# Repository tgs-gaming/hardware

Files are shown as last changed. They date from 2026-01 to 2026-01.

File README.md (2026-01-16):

# TGS Hardware

TGS Hardware Projects

[Documentation](docs/README.md)

## TGS INPUT board

[INPUT BOARD USAGE MANUAL](docs/tgs_input_board_usage_manual.md)

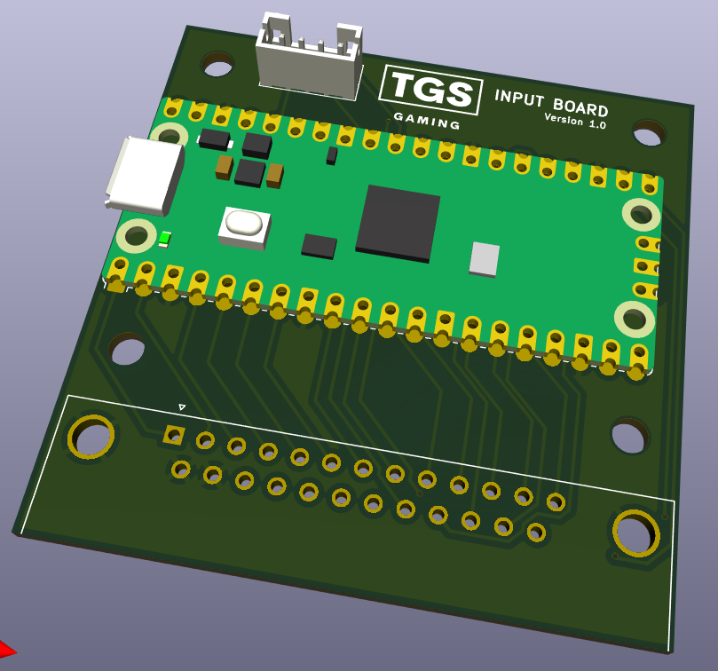
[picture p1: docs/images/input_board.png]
input board
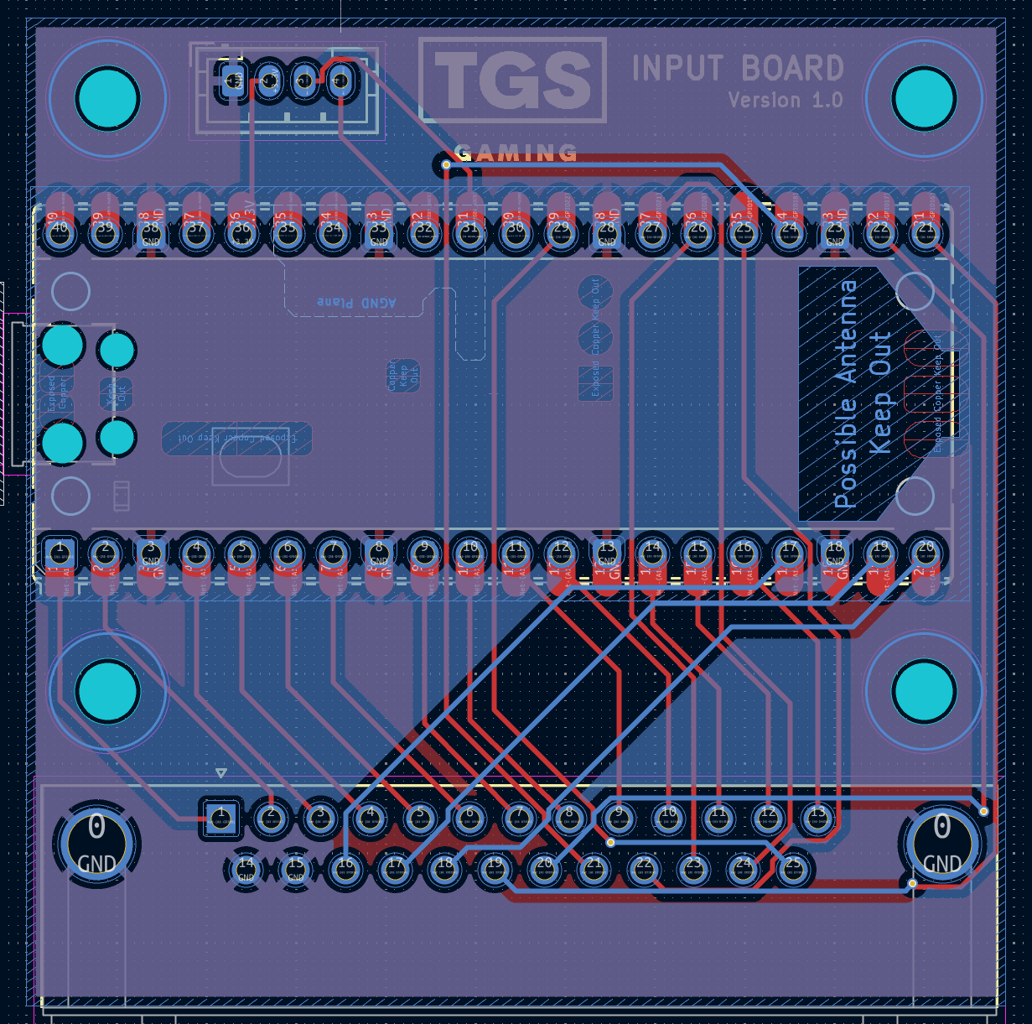
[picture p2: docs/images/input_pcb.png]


Board Configuration Tool

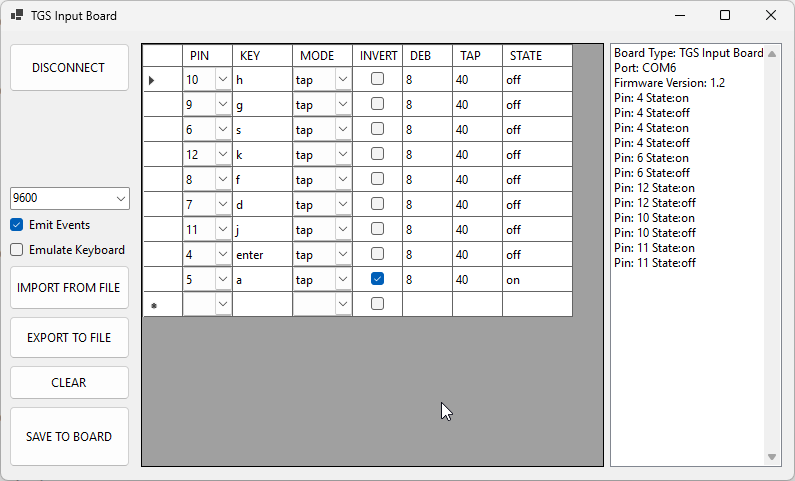
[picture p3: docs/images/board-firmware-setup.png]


## 

## TGS INPUT/OUTPUT board

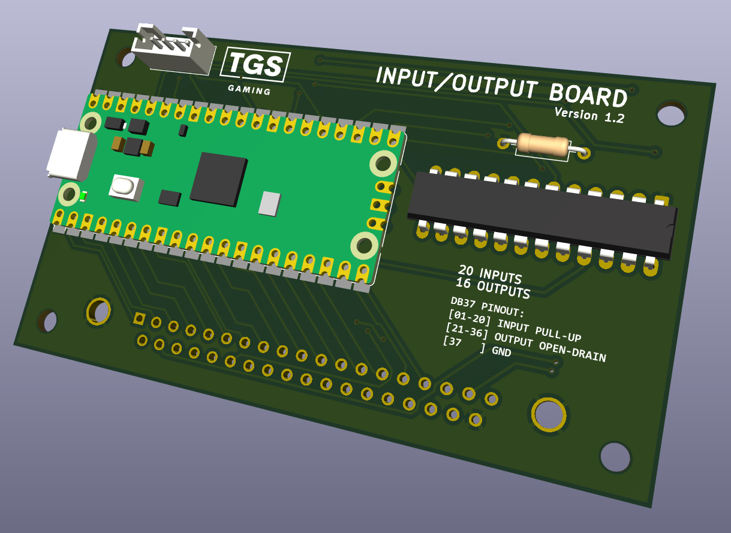
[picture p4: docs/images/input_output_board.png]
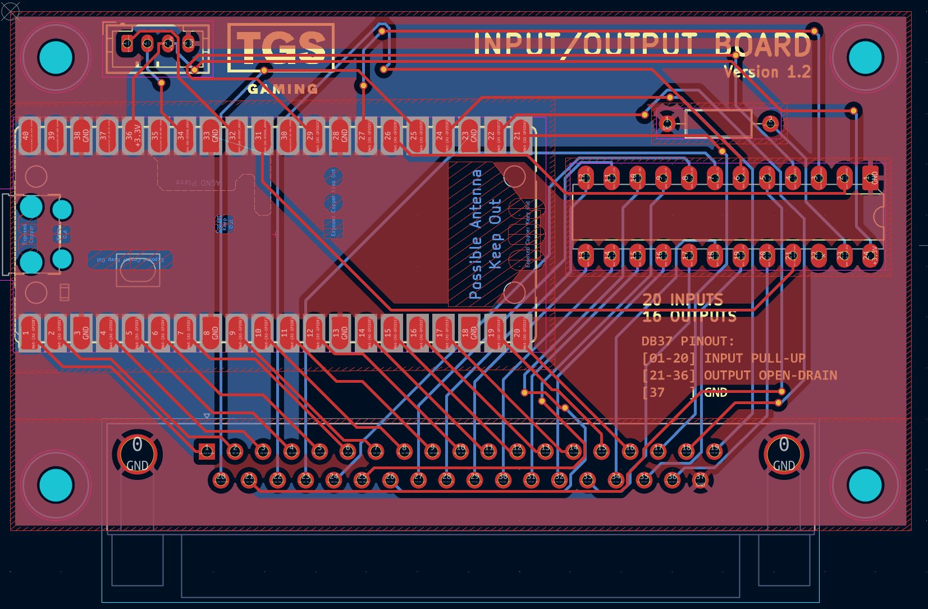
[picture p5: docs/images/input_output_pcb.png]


## TGS OUTPUT board

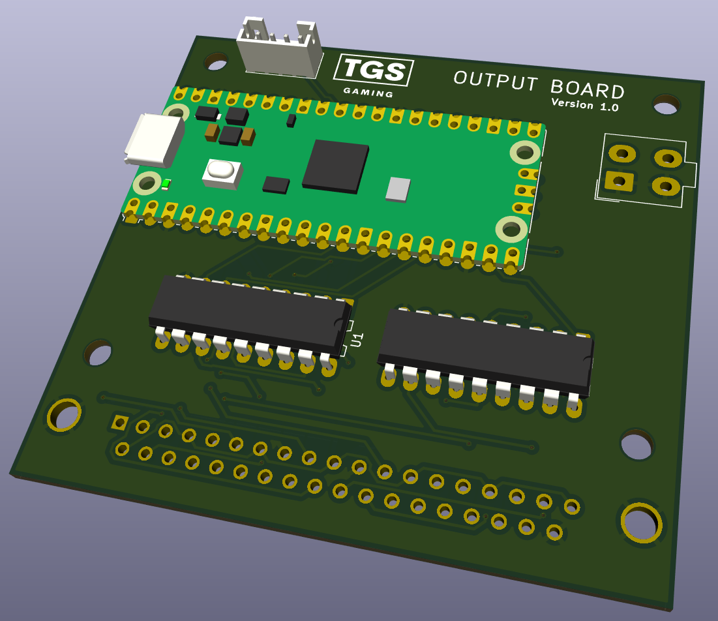
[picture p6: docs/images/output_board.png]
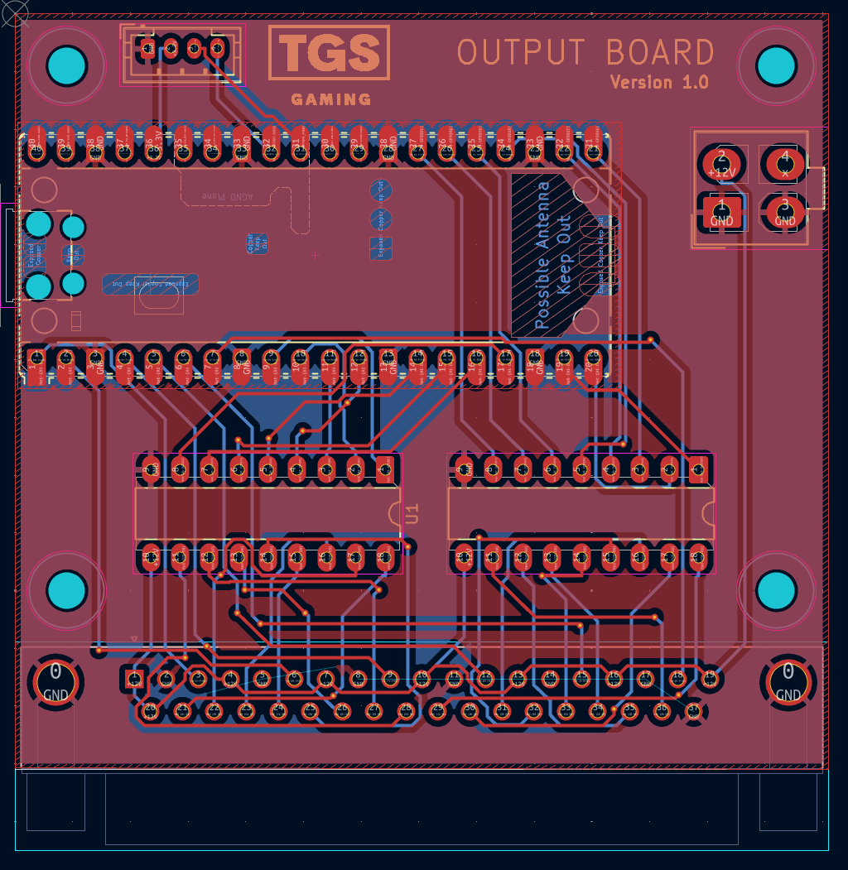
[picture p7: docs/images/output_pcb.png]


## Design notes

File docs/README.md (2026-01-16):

# Documentation

[INPUT BOARD USAGE MANUAL](docs/tgs_input_board_usage_manual.md)

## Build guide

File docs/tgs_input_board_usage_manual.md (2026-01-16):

# TGS Input Board - Usage Manual

Firmware name: TGS Input Board  
Firmware version: 1.2  
Protocol: JSON over Serial (newline-delimited)  
Config persistence: LittleFS (`/tgs_input_config.txt`)  
Inputs supported: Up to 32 configured (hardware may expose fewer)

---

## 1. Overview

The TGS Input Board is a USB-connected input controller designed to read multiple digital inputs (buttons, switches, sensors) and communicate state changes to a host computer.

Each configured input can:

- Emit asynchronous JSON events over Serial
- Optionally act as a USB Keyboard key (press/release)

Configuration is persistent and stored in the board internal filesystem.

---

## 2. Electrical Characteristics

### 2.1 Input Mode

- All inputs use `INPUT_PULLUP`
- Default idle state: `HIGH`
- Active state: `LOW`

### 2.2 Wiring

Typical button wiring:

- One terminal connected to the input pin
- Other terminal connected to GND

Electrical state mapping:

| Electrical level | Reported state |
| --- | --- |
| HIGH | open |
| LOW | closed |

IMPORTANT:  
The `invert` option affects **keyboard logic only**.  
It does **NOT** affect the reported `open/closed` event state.

---

## 3. USB and Serial Interface

- USB interfaces:
  - CDC Serial
  - Optional HID Keyboard
- Default baud rate: `9600`
- Line-based JSON protocol terminated by newline (`\n`)

---

## 4. Message Types

All messages are JSON objects sent/received over Serial.

### 4.1 Responses

Responses always use:

- `type = "resp"`
- `ok = true/false`
- `cmd = "<command>"`

Example OK:

```json
{"type":"resp","ok":true,"cmd":"export"}
```

Example error:

```json
{"type":"resp","ok":false,"cmd":"import","error":"args"}
```

### 4.2 Events

Events always use:

- `type = "event"`
- `pin = <gpio>`
- `state = "open" | "closed"`

Examples:

```json
{"type":"event","pin":12,"state":"closed"}
```

```json
{"type":"event","pin":12,"state":"open"}
```

State meanings:

- `closed`: pin electrically `LOW`
- `open`: pin electrically `HIGH`

---

## 5. Supported Commands

All commands are JSON objects sent over Serial. Each command expects a response message.

### 5.1 board

Request:

```json
{"cmd":"board"}
```

Response:

```json
{"type":"resp","ok":true,"cmd":"board","board":"TGS Input Board"}
```

### 5.2 version

Request:

```json
{"cmd":"version"}
```

Response:

```json
{"type":"resp","ok":true,"cmd":"version","version":"1.2"}
```

### 5.3 export

Returns the full current configuration snapshot.

Request:

```json
{"cmd":"export"}
```

Response (example):

```json
{
  "type": "resp",
  "ok": true,
  "cmd": "export",
  "data": {
    "schema": 1,
    "cfg_ver": 1,
    "baud": 9600,
    "events": false,
    "keyboard": true,
    "buttons": [
      { "pin": 12, "mode": "tap",  "invert": false, "key": "enter", "debounce": 8,  "tap": 40 },
      { "pin": 13, "mode": "hold", "invert": true,  "key": "space", "debounce": 10, "tap": 40 }
    ]
  }
}
```

Notes:

- `schema` identifies the JSON export/import format.
- `cfg_ver` identifies the persisted config file format/version used by the firmware.

### 5.4 import

Replaces the full configuration in one operation (baud/events/keyboard/buttons).

Request (example):

```json
{
  "cmd": "import",
  "data": {
    "schema": 1,
    "baud": 9600,
    "events": true,
    "keyboard": true,
    "buttons": [
      { "pin": 12, "mode": "tap",  "invert": false, "key": "1",     "debounce": 8, "tap": 40 },
      { "pin": 13, "mode": "hold", "invert": false, "key": "enter", "debounce": 8, "tap": 40 }
    ]
  }
}
```

Response:

```json
{"type":"resp","ok":true,"cmd":"import"}
```

If `baud` changes, the board restarts Serial after acknowledging the command.

### 5.5 reset

Resets configuration to defaults and rewrites the config file.

Request:

```json
{"cmd":"reset"}
```

Response:

```json
{"type":"resp","ok":true,"cmd":"reset"}
```

---

## 6. Input Modes

### 6.1 Tap Mode

- Key is pressed when the input becomes active (logical ON)
- Held for the configured `tap` duration (ms)
- Automatically released

### 6.2 Hold Mode

- Key is pressed while the input is active (logical ON)
- Released when input becomes inactive (logical OFF)

---

## 7. Keyboard Key Mapping

The `key` field is a string.

### 7.1 Single Characters

Examples:

```
a
b
1
9
+
-
```

### 7.2 Special Keys (case-insensitive)

```
enter
tab
esc
space
backspace
del
up
down
left
right
f1 ... f12
```

### 7.3 Numeric scan codes

You can specify numeric codes using:

- `"code:<number>"` (recommended)
- `"<number>"` (digits-only string)

Examples:

```
code:176
176
```

---

## 8. Typical Setup Procedure

1. Connect the board via USB
2. Open a Serial terminal at `9600` baud
3. Identify the board

```json
{"cmd":"board"}
```

4. Read current configuration

```json
{"cmd":"export"}
```

5. Apply full configuration (including events + keyboard + buttons)

```json
{"cmd":"import","data":{"schema":1,"baud":9600,"events":true,"keyboard":true,"buttons":[...]}}
```

6. Verify applied configuration

```json
{"cmd":"export"}
```

7. Listen for events (if enabled)

Events arrive asynchronously, interleaved with responses:

```json
{"type":"event","pin":12,"state":"closed"}
```

---

## 9. Troubleshooting

### No events received

- Ensure `events` is `true` in your last `import`
- Verify host is reading line-delimited messages (`\n` terminated)
- Confirm you are connected to the correct Serial port

### Button state appears inverted

- Verify wiring (INPUT_PULLUP expects GND when pressed)
- Use `invert` only to invert the **keyboard** logic if needed

### Double triggers or noise

- Increase `debounce` time

### Keyboard output not working

- Ensure `keyboard` is `true` in your last `import`
- Verify the `key` string is valid

### Settings not persisting after reboot

- Firmware uses `cfg_ver` in the config file header; when it changes, stored config is reset
- Confirm `export` after reboot matches what you imported

---

## 10. Notes

- Firmware supports up to 32 configured inputs
- Configuration file path: `/tgs_input_config.txt`
- All settings persist across reboots (unless `cfg_ver` changes)

---

End of document

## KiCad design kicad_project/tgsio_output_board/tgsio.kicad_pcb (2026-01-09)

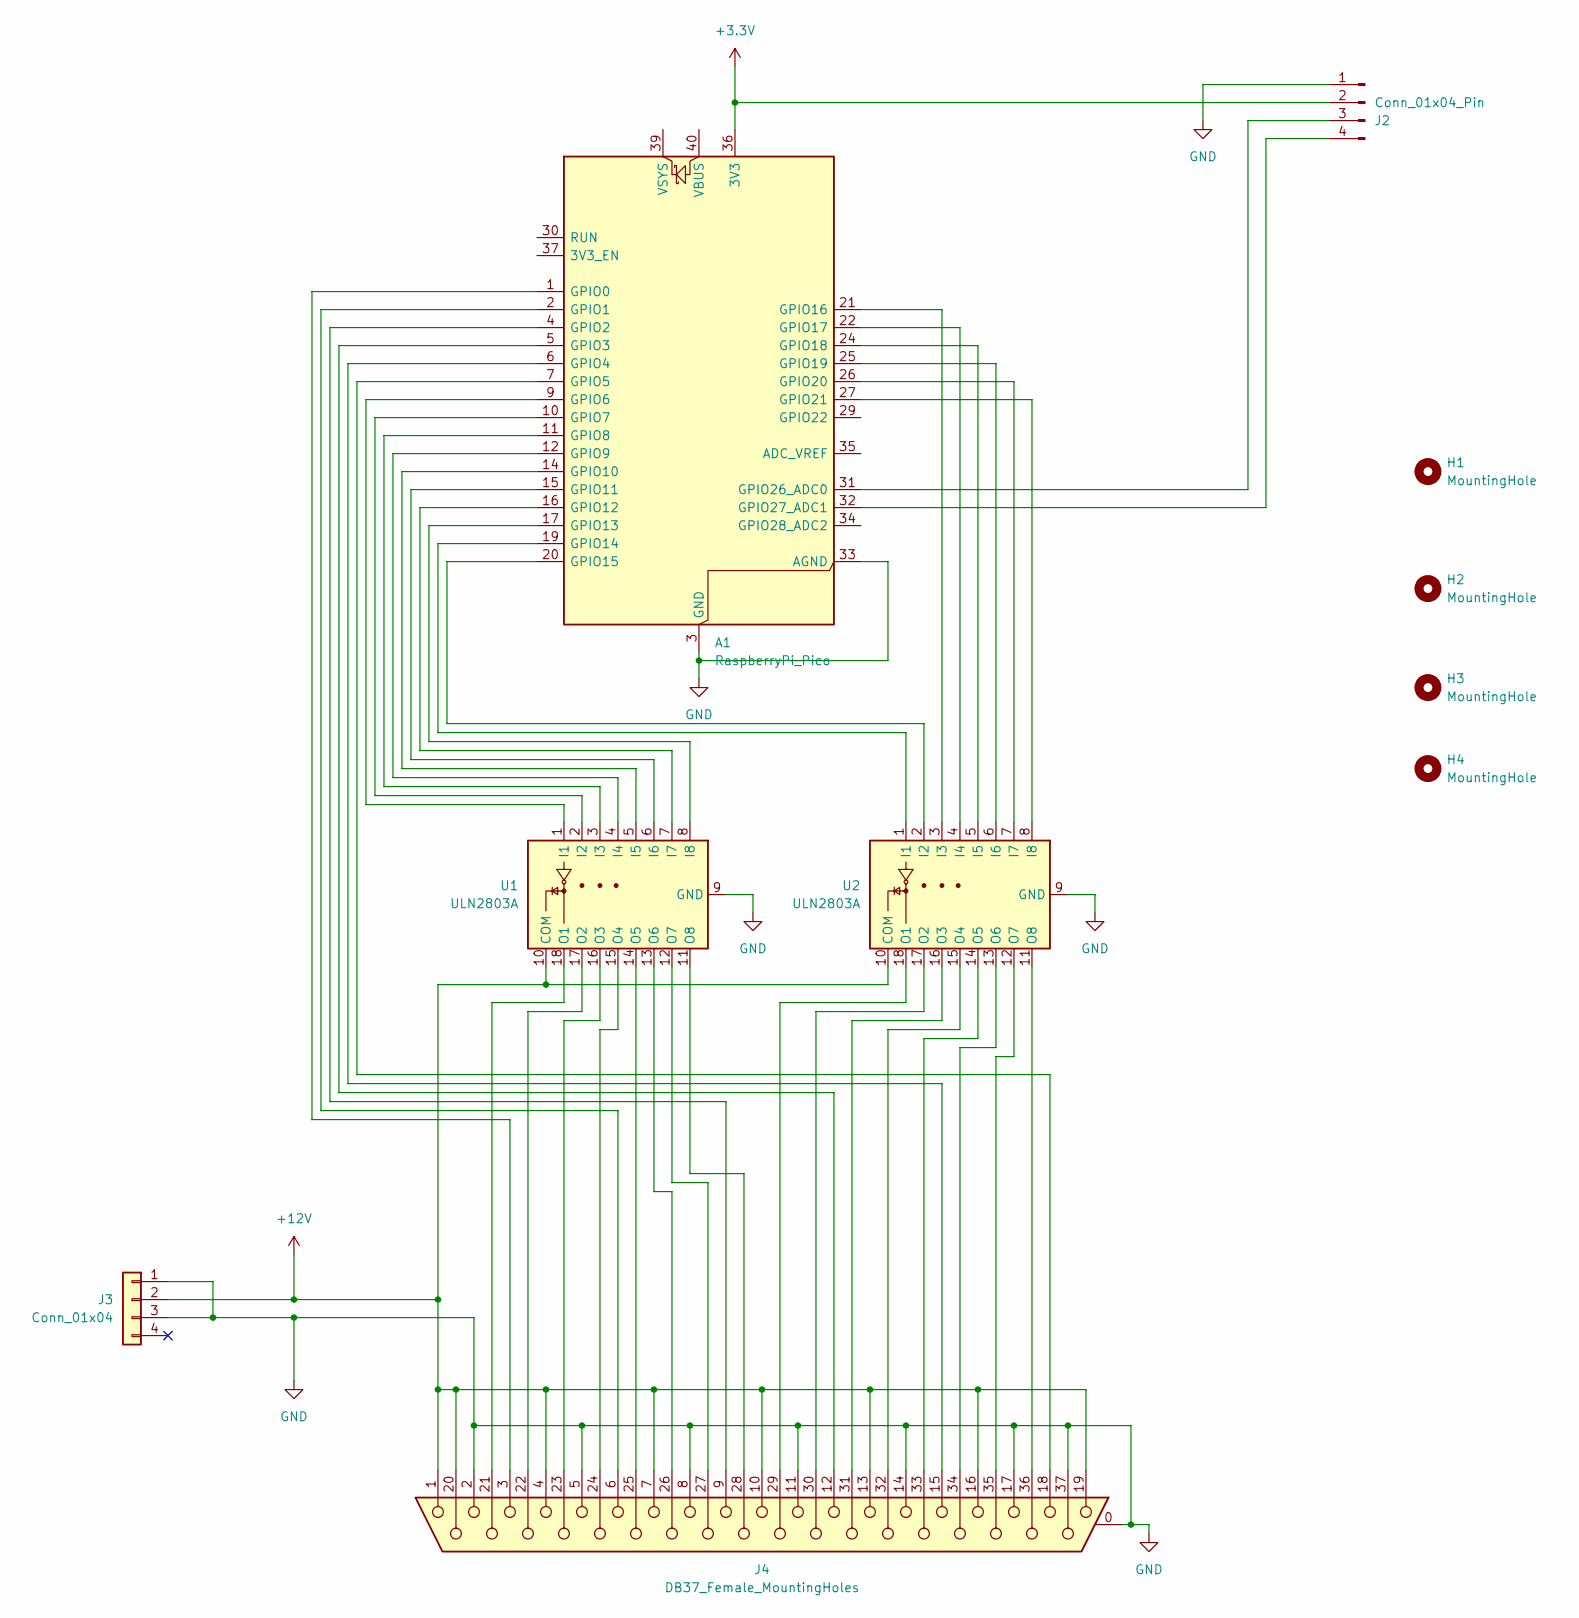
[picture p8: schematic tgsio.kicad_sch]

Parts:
A1: RaspberryPi_Pico; RaspberryPi_Pico_Common_Unspecified
H1, H2, H3, H4: MountingHole; MountingHole_3.2mm_M3
J2: Conn_01x04_Pin; JST_PH_B4B-PH-K_1x04_P2.00mm_Vertical
J3: Conn_01x04; Molex_Mini-Fit_Jr_5566-04A_2x02_P4.20mm_Vertical
J4: DB37_Female_MountingHoles; DSUB-37_Female_Horizontal_P2.77x2.84mm_EdgePinOffset4.94mm_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
U1, U2: ULN2803A; DIP-18_W7.62mm_LongPads

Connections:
+3.3V: A1.36 (3V3), J2.2
+12V: J3.2, J4.1, J4.4, J4.7, J4.10, J4.13, J4.16, J4.19, J4.20, U1.10 (COM), U2.10 (COM)
GND: A1.3 (GND), A1.8 (GND), A1.13 (GND), A1.18 (GND), A1.23 (GND), A1.28 (GND), A1.33 (AGND), A1.38 (GND), J2.1, J3.1, J3.3, J4.0 (PAD), J4.2, J4.5, J4.8, J4.11, J4.14, J4.17, J4.37, U1.9 (GND), U2.9 (GND)
unnamed: A1.1 (GPIO0), J4.3
unnamed: A1.2 (GPIO1), J4.6
unnamed: A1.4 (GPIO2), J4.9
unnamed: A1.5 (GPIO3), J4.12
unnamed: A1.6 (GPIO4), J4.15
unnamed: A1.7 (GPIO5), J4.18
unnamed: A1.9 (GPIO6), U1.1 (I1)
unnamed: A1.10 (GPIO7), U1.2 (I2)
unnamed: A1.11 (GPIO8), U1.3 (I3)
unnamed: A1.12 (GPIO9), U1.4 (I4)
unnamed: A1.14 (GPIO10), U1.5 (I5)
unnamed: A1.15 (GPIO11), U1.6 (I6)
unnamed: A1.16 (GPIO12), U1.7 (I7)
unnamed: A1.17 (GPIO13), U1.8 (I8)
unnamed: A1.19 (GPIO14), U2.1 (I1)
unnamed: A1.20 (GPIO15), U2.2 (I2)
unnamed: A1.21 (GPIO16), U2.3 (I3)
unnamed: A1.22 (GPIO17), U2.4 (I4)
unnamed: A1.24 (GPIO18), U2.5 (I5)
unnamed: A1.25 (GPIO19), U2.6 (I6)
unnamed: A1.26 (GPIO20), U2.7 (I7)
unnamed: A1.27 (GPIO21), U2.8 (I8)
unnamed: A1.31 (GPIO26_ADC0), J2.3
unnamed: A1.32 (GPIO27_ADC1), J2.4
unnamed: J4.21, U1.18 (O1)
unnamed: J4.22, U1.17 (O2)
unnamed: J4.23, U1.16 (O3)
unnamed: J4.24, U1.15 (O4)
unnamed: J4.25, U1.14 (O5)
unnamed: J4.26, U1.13 (O6)
unnamed: J4.27, U1.12 (O7)
unnamed: J4.28, U1.11 (O8)
unnamed: J4.29, U2.18 (O1)
unnamed: J4.30, U2.17 (O2)
unnamed: J4.31, U2.16 (O3)
unnamed: J4.32, U2.15 (O4)
unnamed: J4.33, U2.14 (O5)
unnamed: J4.34, U2.13 (O6)
unnamed: J4.35, U2.12 (O7)
unnamed: J4.36, U2.11 (O8)

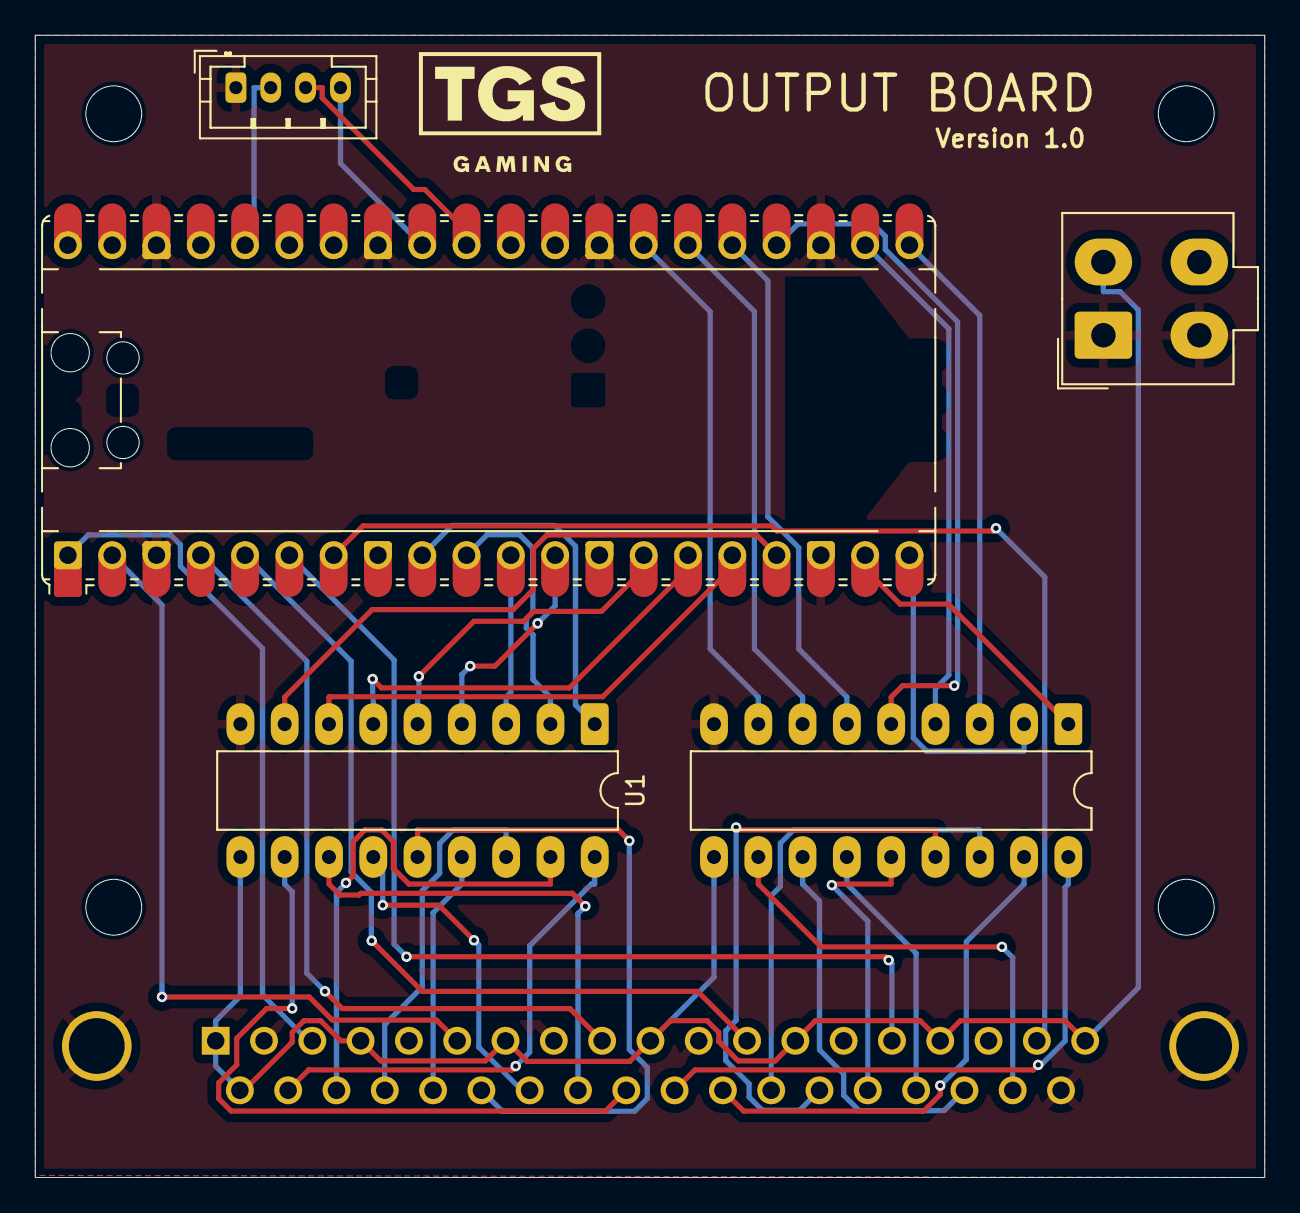
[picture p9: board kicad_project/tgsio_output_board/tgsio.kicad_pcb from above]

Board: 2 copper layers, 70.5 x 65.5 mm, 10 parts (1 on the bottom side), 43 nets.

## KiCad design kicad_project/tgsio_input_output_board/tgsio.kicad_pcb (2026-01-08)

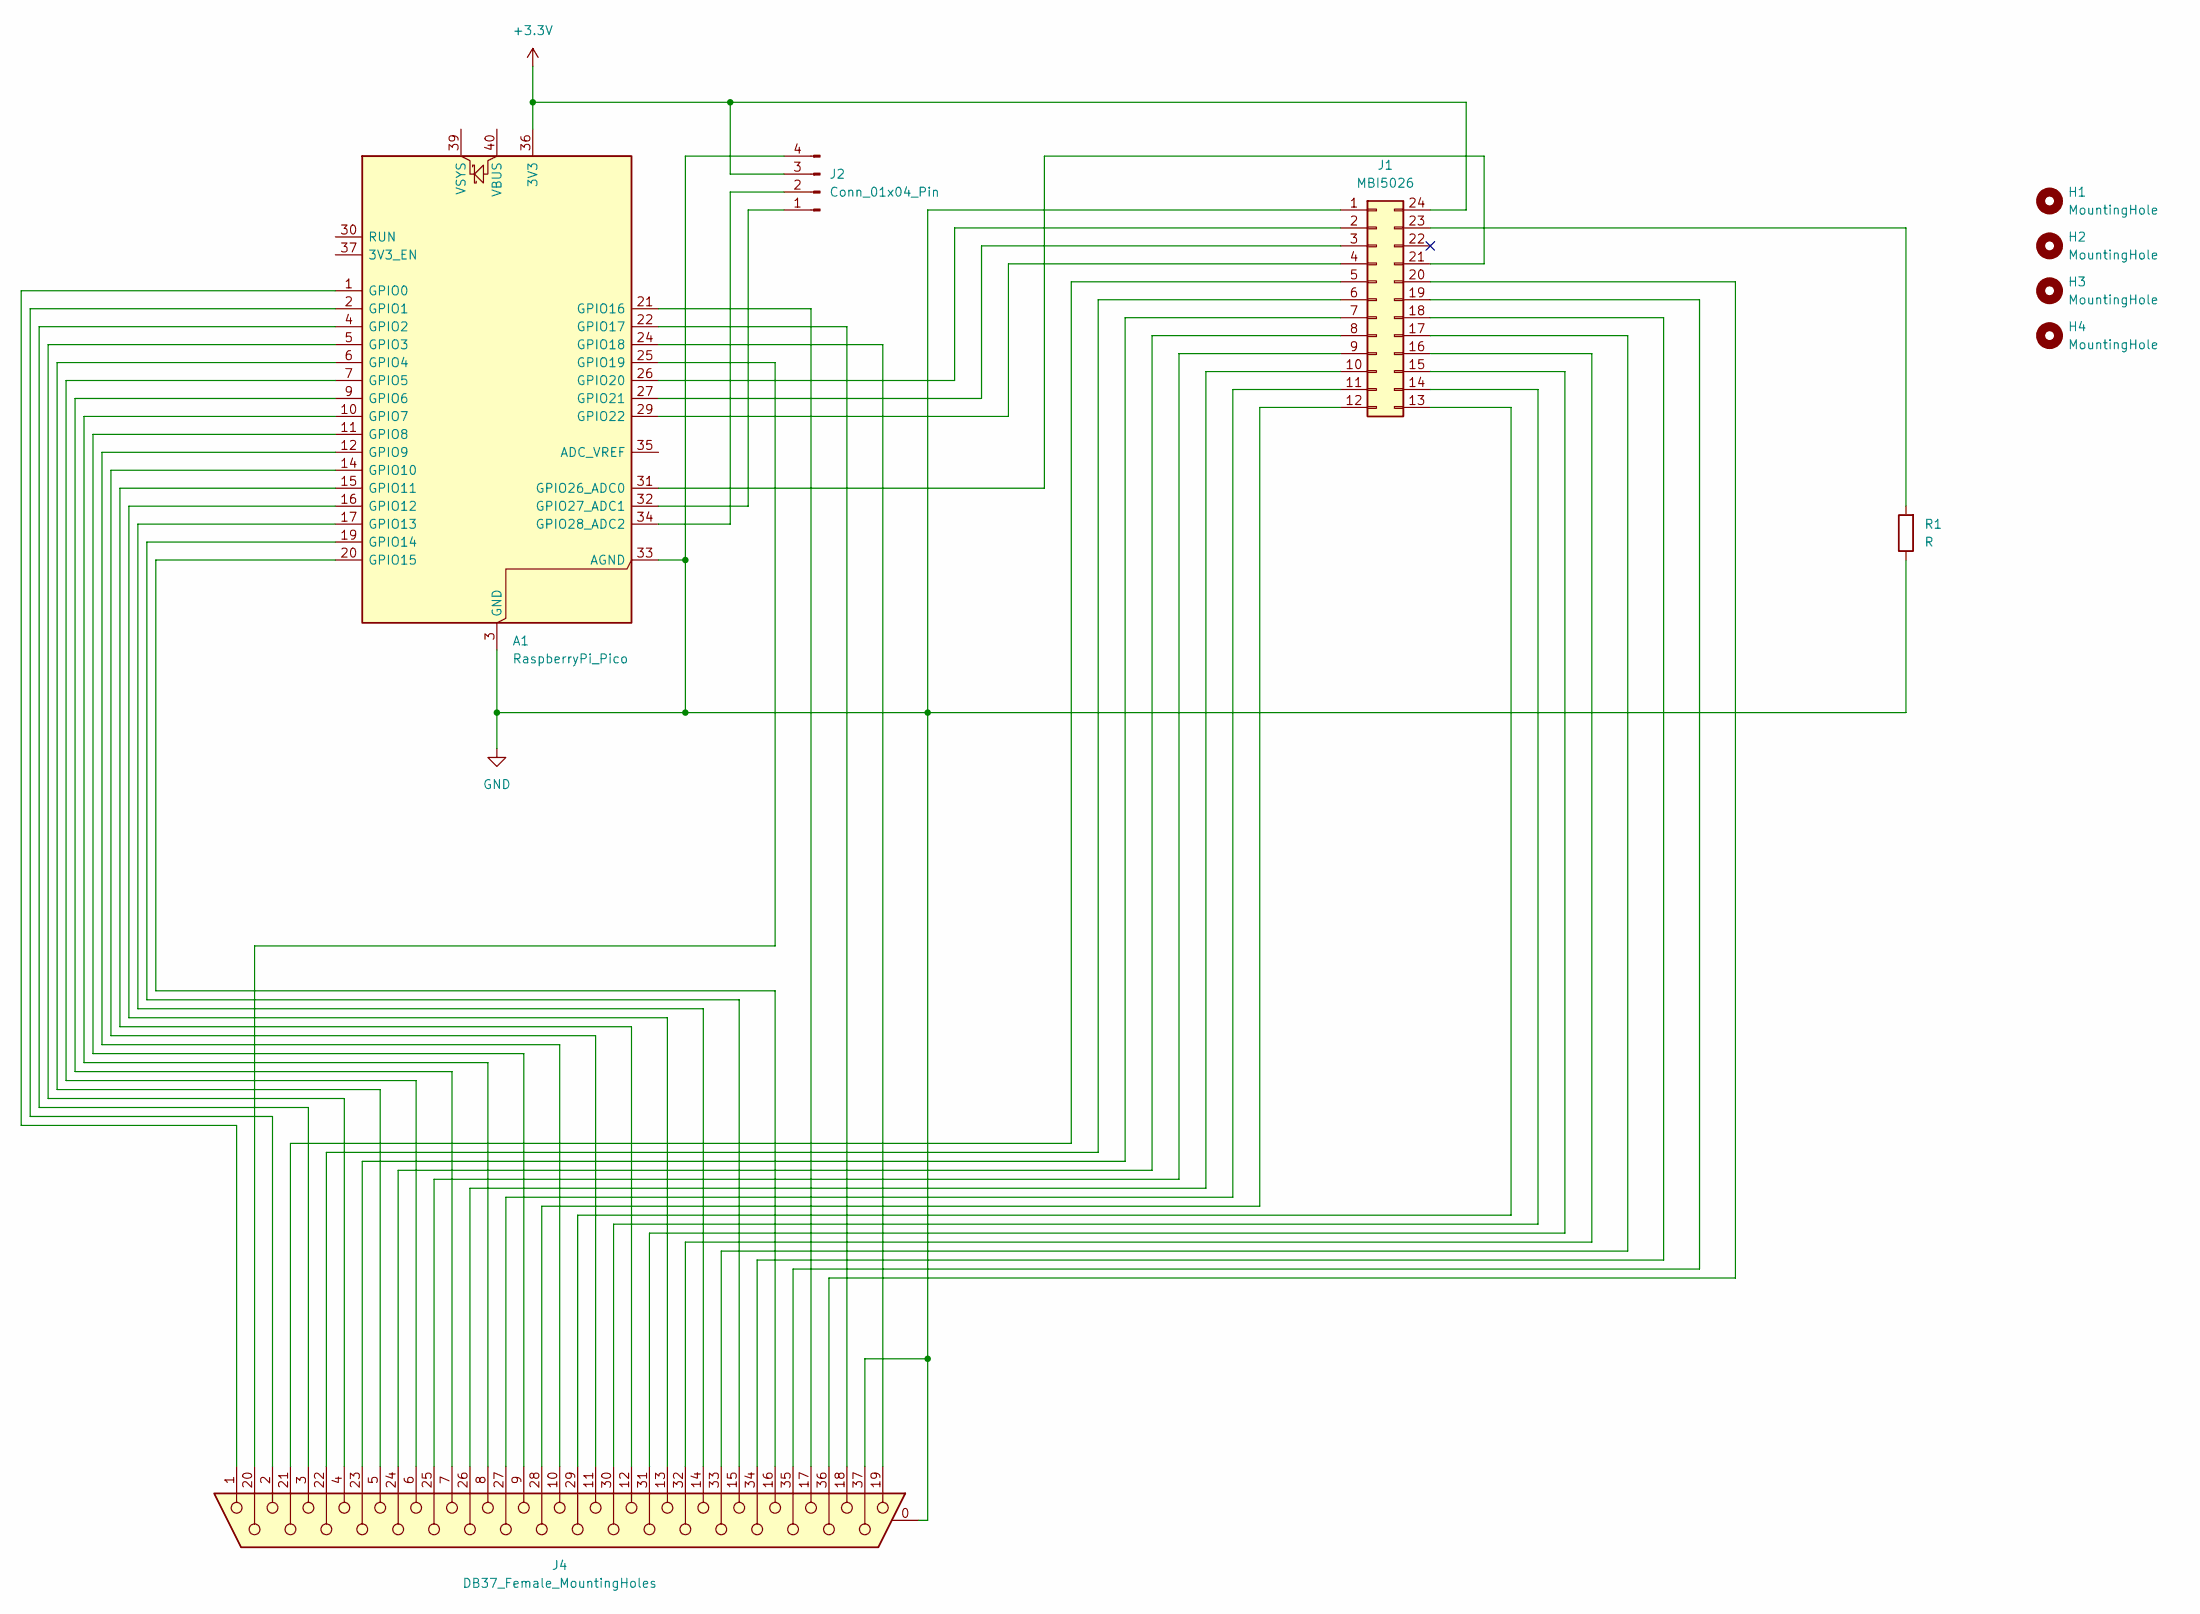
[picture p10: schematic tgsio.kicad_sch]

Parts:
A1: RaspberryPi_Pico; RaspberryPi_Pico_Common_SMD
H1, H2, H3, H4: MountingHole; MountingHole_3.2mm_M3
J1: MBI5026; DIP-24_W7.62mm_LongPads
J2: Conn_01x04_Pin; JST_PH_B4B-PH-K_1x04_P2.00mm_Vertical
J4: DB37_Female_MountingHoles; DSUB-37_Female_Horizontal_P2.77x2.84mm_EdgePinOffset4.94mm_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
R1: R; R_Axial_DIN0207_L6.3mm_D2.5mm_P10.16mm_Horizontal

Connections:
+3.3V: A1.36 (3V3), J1.24, J2.3
GND: A1.3 (GND), A1.8 (GND), A1.13 (GND), A1.18 (GND), A1.23 (GND), A1.28 (GND), A1.33 (AGND), A1.38 (GND), J1.1, J2.4, J4.0 (PAD), J4.37, R1.1
unnamed: A1.1 (GPIO0), J4.1
unnamed: A1.2 (GPIO1), J4.2
unnamed: A1.4 (GPIO2), J4.3
unnamed: A1.5 (GPIO3), J4.4
unnamed: A1.6 (GPIO4), J4.5
unnamed: A1.7 (GPIO5), J4.6
unnamed: A1.9 (GPIO6), J4.7
unnamed: A1.10 (GPIO7), J4.8
unnamed: A1.11 (GPIO8), J4.9
unnamed: A1.12 (GPIO9), J4.10
unnamed: A1.14 (GPIO10), J4.11
unnamed: A1.15 (GPIO11), J4.12
unnamed: A1.16 (GPIO12), J4.13
unnamed: A1.17 (GPIO13), J4.14
unnamed: A1.19 (GPIO14), J4.15
unnamed: A1.20 (GPIO15), J4.16
unnamed: A1.21 (GPIO16), J4.17
unnamed: A1.22 (GPIO17), J4.18
unnamed: A1.24 (GPIO18), J4.19
unnamed: A1.25 (GPIO19), J4.20
unnamed: A1.26 (GPIO20), J1.2
unnamed: A1.27 (GPIO21), J1.3
unnamed: A1.29 (GPIO22), J1.4
unnamed: A1.31 (GPIO26_ADC0), J1.21
unnamed: A1.32 (GPIO27_ADC1), J2.1
unnamed: A1.34 (GPIO28_ADC2), J2.2
unnamed: J1.5, J4.21
unnamed: J1.6, J4.22
unnamed: J1.7, J4.23
unnamed: J1.8, J4.24
unnamed: J1.9, J4.25
unnamed: J1.10, J4.26
unnamed: J1.11, J4.27
unnamed: J1.12, J4.28
unnamed: J1.13, J4.29
unnamed: J1.14, J4.30
unnamed: J1.15, J4.31
unnamed: J1.16, J4.32
unnamed: J1.17, J4.33
unnamed: J1.18, J4.34
unnamed: J1.19, J4.35
unnamed: J1.20, J4.36
unnamed: J1.23, R1.2

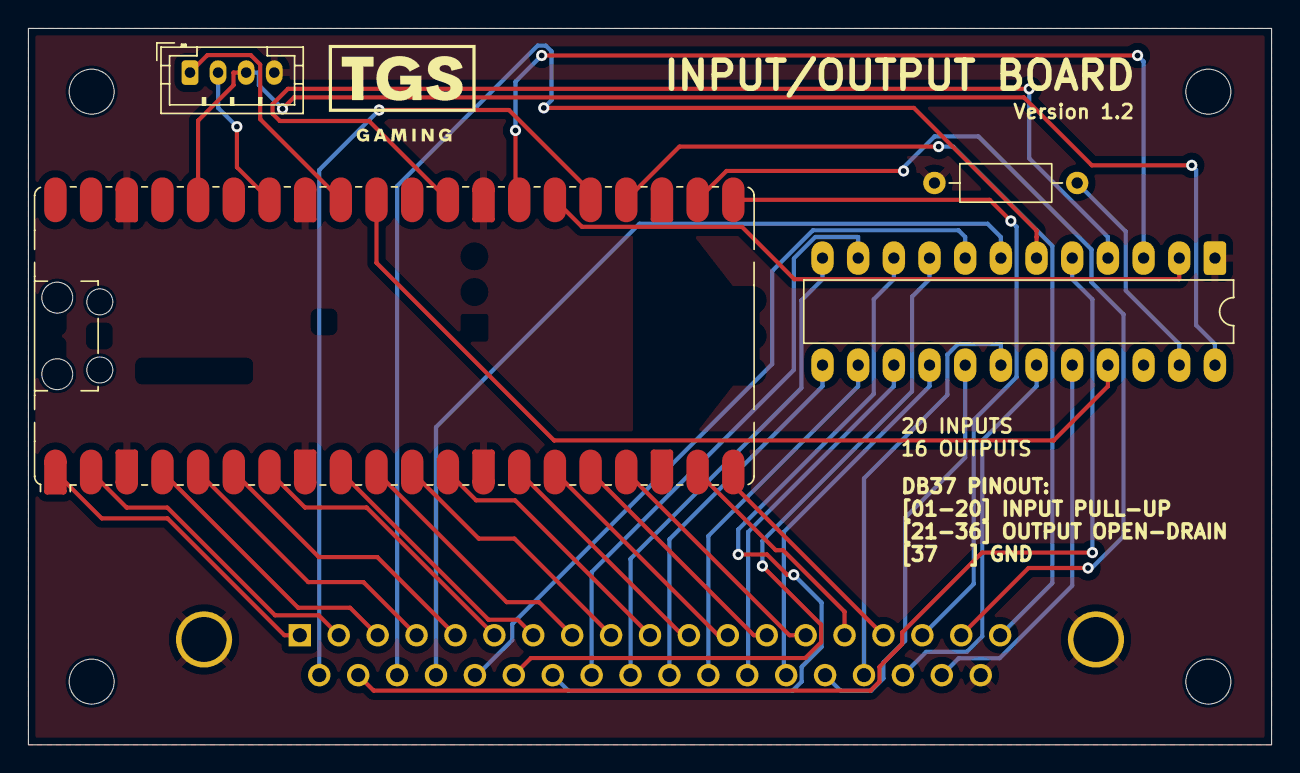
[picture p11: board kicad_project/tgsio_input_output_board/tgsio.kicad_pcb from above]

Board: 2 copper layers, 88.5 x 51.0 mm, 9 parts (1 on the bottom side), 45 nets.

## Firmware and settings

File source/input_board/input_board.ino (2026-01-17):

#include <Bounce2.h>
#include <Keyboard.h>
#include <LittleFS.h>
#include <ArduinoJson.h>

#define FW_NAME "TGS Input Board"
#define FW_VERSION "1.2"
#define CONFIG_VERSION 1
#define CONFIG_PATH "/tgs_input_config.txt"

static const uint16_t RX_LIMIT = 8192;
static const size_t JSON_CAPACITY = 16384;

enum Mode : uint8_t { Tap = 0, Hold = 1 };

struct ButtonConfig {
  uint8_t pin;
  uint8_t mode;
  uint8_t invert;
  uint16_t key;
  uint16_t debounceMillis;
  uint16_t tapMillis;
};

struct ButtonRuntime {
  ButtonConfig config;
  Bounce debounce;
  bool holding;
  bool lastRawClosed;
  bool lastLogicalOn;
  bool isTapping;
  uint32_t tapStart;
};

static const uint8_t MAX_BUTTONS = 32;
ButtonRuntime buttons[MAX_BUTTONS];
uint8_t buttonCount = 0;

bool eventsEnabled = false;
bool keyboardEnabled = true;
bool inResponse = false;

uint32_t serialBaud = 9600;

uint32_t pendingMask = 0;
bool pendingClosed[MAX_BUTTONS];

String rx;

static inline uint8_t ctz32(uint32_t v) { return (uint8_t)__builtin_ctz(v); }

static inline char lowerChar(char c) {
  if (c >= 'A' && c <= 'Z') return (char)(c - 'A' + 'a');
  return c;
}

static inline String toLowerCopy(const String& s) {
  String r = s;
  for (uint16_t i = 0; i < r.length(); i++) r.setCharAt(i, lowerChar(r.charAt(i)));
  return r;
}

static inline void printJsonEscaped(const String& s) {
  for (uint16_t i = 0; i < s.length(); i++) {
    char c = s.charAt(i);
    switch (c) {
      case '\"': Serial.print("\\\""); break;
      case '\\': Serial.print("\\\\"); break;
      case '\b': Serial.print("\\b"); break;
      case '\f': Serial.print("\\f"); break;
      case '\n': Serial.print("\\n"); break;
      case '\r': Serial.print("\\r"); break;
      case '\t': Serial.print("\\t"); break;
      default:
        if ((uint8_t)c < 0x20) {
          Serial.print("\\u00");
          const char* hex = "0123456789abcdef";
          Serial.print(hex[((uint8_t)c >> 4) & 0xF]);
          Serial.print(hex[((uint8_t)c >> 0) & 0xF]);
        } else {
          Serial.print(c);
        }
        break;
    }
  }
}

static inline String keyToString(uint16_t k) {
  if (!k) return "";
  if (k == (uint16_t)' ') return "space";

  switch (k) {
    case KEY_RETURN: return "enter";
    case KEY_TAB: return "tab";
    case KEY_ESC: return "esc";
    case KEY_BACKSPACE: return "backspace";
    case KEY_DELETE: return "del";
    case KEY_UP_ARROW: return "up";
    case KEY_DOWN_ARROW: return "down";
    case KEY_LEFT_ARROW: return "left";
    case KEY_RIGHT_ARROW: return "right";
    case KEY_F1: return "f1";
    case KEY_F2: return "f2";
    case KEY_F3: return "f3";
    case KEY_F4: return "f4";
    case KEY_F5: return "f5";
    case KEY_F6: return "f6";
    case KEY_F7: return "f7";
    case KEY_F8: return "f8";
    case KEY_F9: return "f9";
    case KEY_F10: return "f10";
    case KEY_F11: return "f11";
    case KEY_F12: return "f12";
  }

  if (k >= 32 && k <= 126) {
    String s;
    s += (char)k;
    return s;
  }

  String s = "code:";
  s += String((unsigned)k);
  return s;
}

uint16_t parseKey(const String& in) {
  String s = in;
  s.trim();
  if (!s.length()) return 0;

  if (s.length() >= 5) {
    String p = s.substring(0, 5);
    p = toLowerCopy(p);
    if (p == "code:") {
      String n = s.substring(5);
      n.trim();
      bool ok = true;
      for (uint16_t i = 0; i < n.length(); i++) {
        char c = n.charAt(i);
        if (c < '0' || c > '9') { ok = false; break; }
      }
      if (ok && n.length()) {
        unsigned long v = n.toInt();
        if (v > 0 && v <= 65535) return (uint16_t)v;
      }
      return 0;
    }
  }

  bool allDigits = true;
  for (uint16_t i = 0; i < s.length(); i++) {
    char c = s.charAt(i);
    if (c < '0' || c > '9') { allDigits = false; break; }
  }
  if (allDigits) {
    unsigned long v = s.toInt();
    if (v > 0 && v <= 65535) return (uint16_t)v;
    return 0;
  }

  if (s.length() == 1) return (uint8_t)s[0];

  s = toLowerCopy(s);

  if (s == "enter") return KEY_RETURN;
  if (s == "tab") return KEY_TAB;
  if (s == "esc") return KEY_ESC;
  if (s == "space") return (uint16_t)' ';
  if (s == "backspace") return KEY_BACKSPACE;
  if (s == "del") return KEY_DELETE;

  if (s == "up") return KEY_UP_ARROW;
  if (s == "down") return KEY_DOWN_ARROW;
  if (s == "left") return KEY_LEFT_ARROW;
  if (s == "right") return KEY_RIGHT_ARROW;

  if (s == "f1") return KEY_F1;
  if (s == "f2") return KEY_F2;
  if (s == "f3") return KEY_F3;
  if (s == "f4") return KEY_F4;
  if (s == "f5") return KEY_F5;
  if (s == "f6") return KEY_F6;
  if (s == "f7") return KEY_F7;
  if (s == "f8") return KEY_F8;
  if (s == "f9") return KEY_F9;
  if (s == "f10") return KEY_F10;
  if (s == "f11") return KEY_F11;
  if (s == "f12") return KEY_F12;

  return 0;
}

bool parseModeStr(const String& in, uint8_t& outMode) {
  String s = toLowerCopy(in);
  if (s == "tap") { outMode = Tap; return true; }
  if (s == "hold") { outMode = Hold; return true; }
  return false;
}

static const uint8_t MAX_VPINS = 32;
static const int8_t V2G[MAX_VPINS] = {
  0,  1,  2,  3,  4,  5,  6,  7,  8,  9,  10, 11, 12,
  -1, -1,
  13, 14, 15, 16, 17, 18, 19, 20, 21, 22, 23, 24, 25, 26, 27, 28, 29
};

static inline bool vpinToGpio(int vpin, uint8_t& gpioOut) {
  if (vpin < 1 || vpin > (int)MAX_VPINS) return false;
  int8_t g = V2G[vpin - 1];
  if (g < 0 || g > 29) return false;
  gpioOut = (uint8_t)g;
  return true;
}

static inline int gpioToVpin(uint8_t gpio) {
  for (int i = 0; i < (int)MAX_VPINS; i++) {
    if (V2G[i] == (int8_t)gpio) return i + 1;
  }
  return 0;
}

void saveConfig() {
  File f = LittleFS.open(CONFIG_PATH, "w");
  if (!f) return;

  f.printf("v%d %u %u %u %lu\n",
    CONFIG_VERSION,
    (unsigned)buttonCount,
    (unsigned)(eventsEnabled ? 1 : 0),
    (unsigned)(keyboardEnabled ? 1 : 0),
    (unsigned long)serialBaud
  );

  for (uint8_t i = 0; i < buttonCount; i++) {
    auto& c = buttons[i].config;
    f.printf("%u %u %u %u %u %u\n",
      (unsigned)c.pin,
      (unsigned)c.mode,
      (unsigned)c.invert,
      (unsigned)c.key,
      (unsigned)c.debounceMillis,
      (unsigned)c.tapMillis
    );
  }

  f.flush();
  f.close();
}

void defaults() {
  buttonCount = 0;
  eventsEnabled = false;
  keyboardEnabled = true;
  serialBaud = 9600;
  pendingMask = 0;
}

void applyOne(uint8_t i) {
  auto& b = buttons[i];
  pinMode(b.config.pin, INPUT_PULLUP);
  b.debounce.attach(b.config.pin);
  b.debounce.interval(b.config.debounceMillis);

  b.holding = false;
  b.isTapping = false;
  b.tapStart = 0;

  b.debounce.update();
  bool rawClosed = (b.debounce.read() == LOW);
  bool logicalOn = b.config.invert ? !rawClosed : rawClosed;

  b.lastRawClosed = rawClosed;
  b.lastLogicalOn = logicalOn;
}

void applyAll() {
  for (uint8_t i = 0; i < buttonCount; i++) applyOne(i);
}

void resetConfigStorage() {
  defaults();
  LittleFS.remove(CONFIG_PATH);
  saveConfig();
  applyAll();
}

bool loadConfig() {
  if (!LittleFS.exists(CONFIG_PATH)) return true;

  File f = LittleFS.open(CONFIG_PATH, "r");
  if (!f) return false;

  String header = f.readStringUntil('\n');
  header.trim();

  int v = 0, cnt = 0, ev = 0, kb = 1;
  unsigned long b = 9600;

  if (sscanf(header.c_str(), "v%d %d %d %d %lu", &v, &cnt, &ev, &kb, &b) != 5) {
    f.close();
    return false;
  }

  if (v != CONFIG_VERSION) {
    f.close();
    return false;
  }

  eventsEnabled = (ev != 0);
  keyboardEnabled = (kb != 0);
  serialBaud = (uint32_t)b;

  buttonCount = 0;

  while (f.available() && buttonCount < MAX_BUTTONS) {
    String line = f.readStringUntil('\n');
    line.trim();
    if (!line.length()) continue;

    int pin, mode, inv;
    unsigned key;
    int deb, tap;

    if (sscanf(line.c_str(), "%d %d %d %u %d %d", &pin, &mode, &inv, &key, &deb, &tap) == 6) {
      if (pin < 0 || pin > 29) continue;
      auto& c = buttons[buttonCount].config;
      c.pin = (uint8_t)pin;
      c.mode = (uint8_t)mode;
      c.invert = (uint8_t)inv;
      c.key = (uint16_t)key;
      c.debounceMillis = (uint16_t)deb;
      c.tapMillis = (uint16_t)tap;
      buttonCount++;
    }
  }

  f.close();
  applyAll();
  return true;
}

void respondError(const char* cmd, const char* err) {
  Serial.print("{\"type\":\"resp\",\"ok\":false,\"cmd\":\"");
  Serial.print(cmd);
  Serial.print("\",\"error\":\"");
  Serial.print(err);
  Serial.println("\"}");
}

void respondOk(const char* cmd) {
  Serial.print("{\"type\":\"resp\",\"ok\":true,\"cmd\":\"");
  Serial.print(cmd);
  Serial.println("\"}");
}

void respondBoard() {
  Serial.print("{\"type\":\"resp\",\"ok\":true,\"cmd\":\"board\",\"board\":\"");
  Serial.print(FW_NAME);
  Serial.println("\"}");
}

void respondVersion() {
  Serial.print("{\"type\":\"resp\",\"ok\":true,\"cmd\":\"version\",\"version\":\"");
  Serial.print(FW_VERSION);
  Serial.println("\"}");
}

void respondExport() {
  Serial.print("{\"type\":\"resp\",\"ok\":true,\"cmd\":\"export\",\"data\":{");
  Serial.print("\"schema\":1,");
  Serial.print("\"cfg_ver\":"); Serial.print(CONFIG_VERSION); Serial.print(",");
  Serial.print("\"baud\":"); Serial.print(serialBaud); Serial.print(",");
  Serial.print("\"events\":"); Serial.print(eventsEnabled ? "true" : "false"); Serial.print(",");
  Serial.print("\"keyboard\":"); Serial.print(keyboardEnabled ? "true" : "false"); Serial.print(",");
  Serial.print("\"buttons\":[");
  for (uint8_t i = 0; i < buttonCount; i++) {
    auto& c = buttons[i].config;
    int vpin = gpioToVpin(c.pin);
    if (i) Serial.print(",");
    Serial.print("{\"pin\":"); Serial.print(vpin);
    Serial.print(",\"mode\":\""); Serial.print(c.mode == Hold ? "hold" : "tap");
    Serial.print("\",\"invert\":"); Serial.print(c.invert ? "true" : "false");
    Serial.print(",\"key\":\"");
    String ks = keyToString(c.key);
    printJsonEscaped(ks);
    Serial.print("\"");
    Serial.print(",\"debounce\":"); Serial.print(c.debounceMillis);
    Serial.print(",\"tap\":"); Serial.print(c.tapMillis);
    Serial.print("}");
  }
  Serial.println("]}}");
}

bool applyImport(JsonVariant dataVar, uint32_t& newBaudOut, bool& baudChangedOut) {
  if (dataVar.isNull() || !dataVar.is<JsonObject>()) return false;

  JsonObject data = dataVar.as<JsonObject>();

  uint32_t newBaud = data["baud"] | serialBaud;
  if (newBaud < 300 || newBaud > 3000000) return false;

  bool newEvents = data["events"] | eventsEnabled;
  bool newKeyboard = data["keyboard"] | keyboardEnabled;

  JsonArray btns = data["buttons"].as<JsonArray>();
  if (btns.isNull()) return false;
  if (btns.size() > MAX_BUTTONS) return false;

  ButtonConfig temp[MAX_BUTTONS];
  uint8_t tempCount = 0;

  for (JsonVariant v : btns) {
    if (!v.is<JsonObject>()) return false;
    JsonObject o = v.as<JsonObject>();

    int vpin = o["pin"] | -1;
    uint8_t gpio;
    if (!vpinToGpio(vpin, gpio)) return false;

    String modeStr = (const char*)(o["mode"] | "tap");
    uint8_t mode;
    if (!parseModeStr(modeStr, mode)) return false;

    bool inv = o["invert"] | false;

    String keyStr = (const char*)(o["key"] | "");
    uint16_t key = parseKey(keyStr);
    if (!key) return false;

    uint16_t deb = (uint16_t)(o["debounce"] | 8);
    uint16_t tap = (uint16_t)(o["tap"] | 40);

    for (uint8_t i = 0; i < tempCount; i++) {
      if (temp[i].pin == gpio) return false;
    }

    temp[tempCount].pin = gpio;
    temp[tempCount].mode = mode;
    temp[tempCount].invert = inv ? 1 : 0;
    temp[tempCount].key = key;
    temp[tempCount].debounceMillis = deb;
    temp[tempCount].tapMillis = tap;
    tempCount++;
  }

  uint32_t oldBaud = serialBaud;

  buttonCount = tempCount;
  for (uint8_t i = 0; i < buttonCount; i++) buttons[i].config = temp[i];

  eventsEnabled = newEvents;
  keyboardEnabled = newKeyboard;
  serialBaud = newBaud;

  pendingMask = 0;

  applyAll();
  saveConfig();

  baudChangedOut = (oldBaud != newBaud);
  newBaudOut = newBaud;
  return true;
}

void emitEvent(uint8_t idx, bool rawClosed) {
  if (!eventsEnabled || !Serial) return;

  bool logicalOn = buttons[idx].config.invert ? !rawClosed : rawClosed;

  if (inResponse) {
    pendingClosed[idx] = rawClosed;
    pendingMask |= (1u << idx);
    buttons[idx].lastLogicalOn = logicalOn;
    return;
  }

  int vpin = gpioToVpin(buttons[idx].config.pin);

  Serial.print("{\"type\":\"event\",\"pin\":");
  Serial.print(vpin);
  Serial.print(",\"state\":\"");
  Serial.print(logicalOn ? "on" : "off");
  Serial.println("\"}");
}

void flushEvents() {
  if (!eventsEnabled || inResponse) return;
  uint32_t m = pendingMask;
  pendingMask = 0;
  while (m) {
    uint8_t i = ctz32(m);
    m &= (m - 1);
    emitEvent(i, pendingClosed[i]);
  }
}

void buildStateSnapshot(uint32_t &logicalMask) {
  logicalMask = 0;

  for (uint8_t i = 0; i < buttonCount; i++) {
    buttons[i].debounce.update();

    bool rawClosed = (buttons[i].debounce.read() == LOW);
    bool logicalOn = buttons[i].config.invert ? !rawClosed : rawClosed;

    buttons[i].lastRawClosed = rawClosed;
    buttons[i].lastLogicalOn = logicalOn;

    if (logicalOn) logicalMask |= (1u << i);
  }
}

void respondSync() {
  uint32_t logicalMask;
  buildStateSnapshot(logicalMask);

  Serial.print("{\"type\":\"resp\",\"ok\":true,\"cmd\":\"sync\"");
  Serial.print(",\"mask\":"); Serial.print(logicalMask);
  Serial.print(",\"states\":[");

  for (uint8_t i = 0; i < buttonCount; i++) {
    int vpin = gpioToVpin(buttons[i].config.pin);
    bool logicalOn = buttons[i].lastLogicalOn;

    if (i) Serial.print(",");
    Serial.print("{\"pin\":"); Serial.print(vpin);
    Serial.print(",\"state\":\""); Serial.print(logicalOn ? "on" : "off");
    Serial.print("\"}");
  }

  Serial.println("]}");
}

void handleJson(const String& line) {
  StaticJsonDocument<JSON_CAPACITY> doc;
  DeserializationError err = deserializeJson(doc, line);
  if (err) return;

  const char* cmd = doc["cmd"] | "";
  inResponse = true;

  if (!strcmp(cmd, "export")) {
    respondExport();

  } else if (!strcmp(cmd, "import")) {
    uint32_t newBaud = serialBaud;
    bool baudChanged = false;

    JsonVariant data = doc["data"];
    if (!applyImport(data, newBaud, baudChanged)) {
      respondError(cmd, "args");
    } else {
      respondOk(cmd);
      if (baudChanged) {
        Serial.flush();
        Serial.end();
        delay(20);
        Serial.begin(newBaud);
        delay(10);
      }
    }

  } else if (!strcmp(cmd, "board")) {
    respondBoard();

  } else if (!strcmp(cmd, "version")) {
    respondVersion();

  } else if (!strcmp(cmd, "sync")) {
    respondSync();

  } else if (!strcmp(cmd, "reset")) {
    resetConfigStorage();
    respondOk(cmd);

  } else {
    respondError(cmd, "cmd");
  }

  inResponse = false;
  flushEvents();
}

void processSerial() {
  while (Serial.available()) {
    char c = (char)Serial.read();
    if (c == '\n') {
      String l = rx;
      rx = "";
      l.trim();
      if (l.length()) handleJson(l);
    } else if (c != '\r') {
      if (rx.length() < RX_LIMIT) rx += c;
    }
  }
}

void processButtons() {
  uint32_t now = millis();
  for (uint8_t i = 0; i < buttonCount; i++) {
    auto& b = buttons[i];
    b.debounce.update();

    if (b.isTapping && (uint32_t)(now - b.tapStart) >= b.config.tapMillis) {
      Keyboard.release((uint8_t)b.config.key);
      b.isTapping = false;
    }

    bool rawClosed = (b.debounce.read() == LOW);
    bool logicalOn = b.config.invert ? !rawClosed : rawClosed;

    if (rawClosed != b.lastRawClosed) {
      b.lastRawClosed = rawClosed;
      emitEvent(i, rawClosed);
    }

    if (!keyboardEnabled) {
      b.lastLogicalOn = logicalOn;
      continue;
    }

    if (logicalOn != b.lastLogicalOn) {
      b.lastLogicalOn = logicalOn;

      if (logicalOn) {
        if (b.config.mode == Tap) {
          Keyboard.press((uint8_t)b.config.key);
          b.tapStart = now;
          b.isTapping = true;
        } else {
          b.holding = true;
          Keyboard.press((uint8_t)b.config.key);
        }
      } else {
        if (b.holding) {
          b.holding = false;
          Keyboard.release((uint8_t)b.config.key);
        }
      }
    }
  }
}

void setup() {
  rx.reserve(256);

  defaults();

  if (!LittleFS.begin()) {
    LittleFS.format();
    LittleFS.begin();
  }

  Keyboard.begin();

  if (!loadConfig()) {
    resetConfigStorage();
  }

  Serial.begin(serialBaud);
  delay(10);
}

void loop() {
  processButtons();
  processSerial();
  flushEvents();
}

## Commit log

2025-12-17 First import, added input board source code
2025-12-17 Added kicad git ignore
2025-12-17 Added kicad project files
    [tgsio.kicad_pcb, tgsio.kicad_sch, tgsio_version_1_0.kicad_sch]
2026-01-08 Updated routed version
    [tgsio.kicad_pcb]
2026-01-08 Added readme
    [tgsio.kicad_pcb, tgsio.kicad_sch, tgsio_version_1_0.kicad_sch]
2026-01-09 Updated routing and README
    [tgsio.kicad_pcb, tgsio.kicad_sch, tgsio_version_1_0.kicad_sch]
2026-01-16 Added board configuration tool and made some protocol changes
